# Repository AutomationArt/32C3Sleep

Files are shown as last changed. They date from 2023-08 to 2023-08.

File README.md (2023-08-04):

# 32C3Sleep for Automation.art
A framework for building your ESP32-c3 based projects. With battery charging and disconnection. 

#### Right away about bugs that were fixed in the scheme after the first prototype) 
!Resistors for the voltage divider should be taken 10kΩ and 39kΩ (R18 | R7), since the esp32c3 can measure 2.5V maximum

###  How does it work?
This board is designed to create projects in hibernation mode or with low power consumption and small size. Additional pins and JTAG are provided for this purpose. The TP4056 charging module discharges the battery in the same way as a self-discharging battery, and features a 3.3V LDO and an external quartz for more accurate timing.

### Main features
- Microcontroller with or without antenna
- Temperature sensor connection pins ds18b20
- Battery connection pins
- Reset button
- 1 indicator LEDs
- Ldo 3.3v

### Examples of use
- Sensor with low consumption and small size
- Any battery operated wifi/ble device
- ESP-NOW / WiFi-Mesh and other mesh technologies

### Current PCB release 
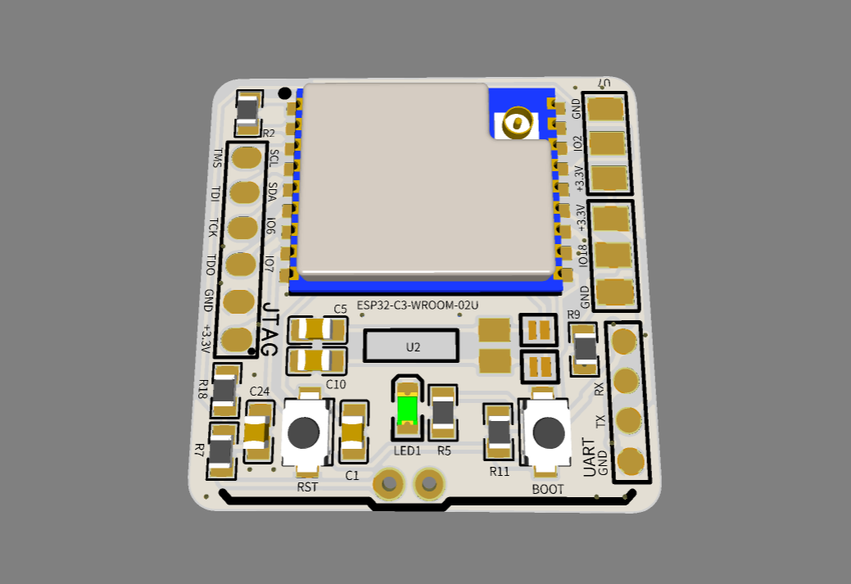
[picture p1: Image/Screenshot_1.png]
  
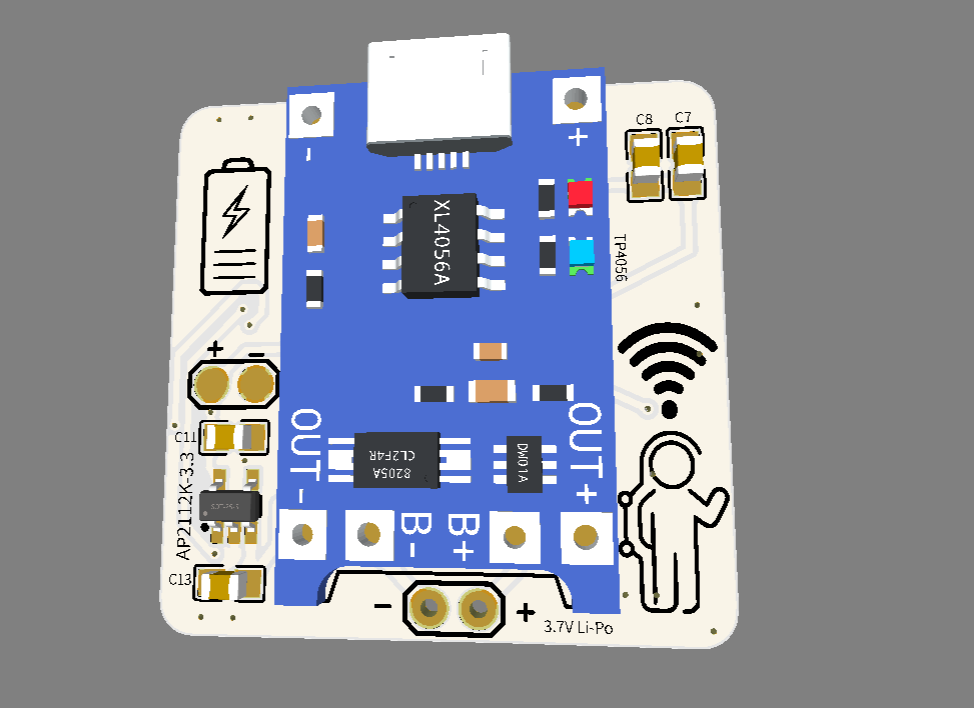
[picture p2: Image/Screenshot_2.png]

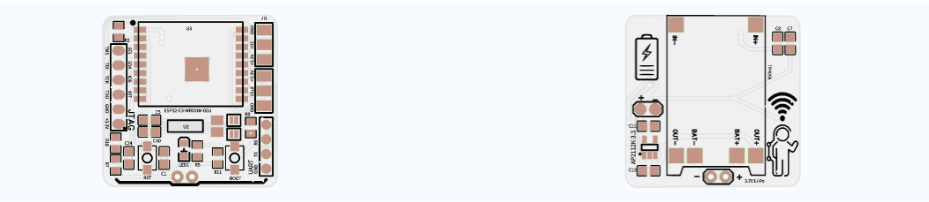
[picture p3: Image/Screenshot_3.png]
  

### Manufactured device 

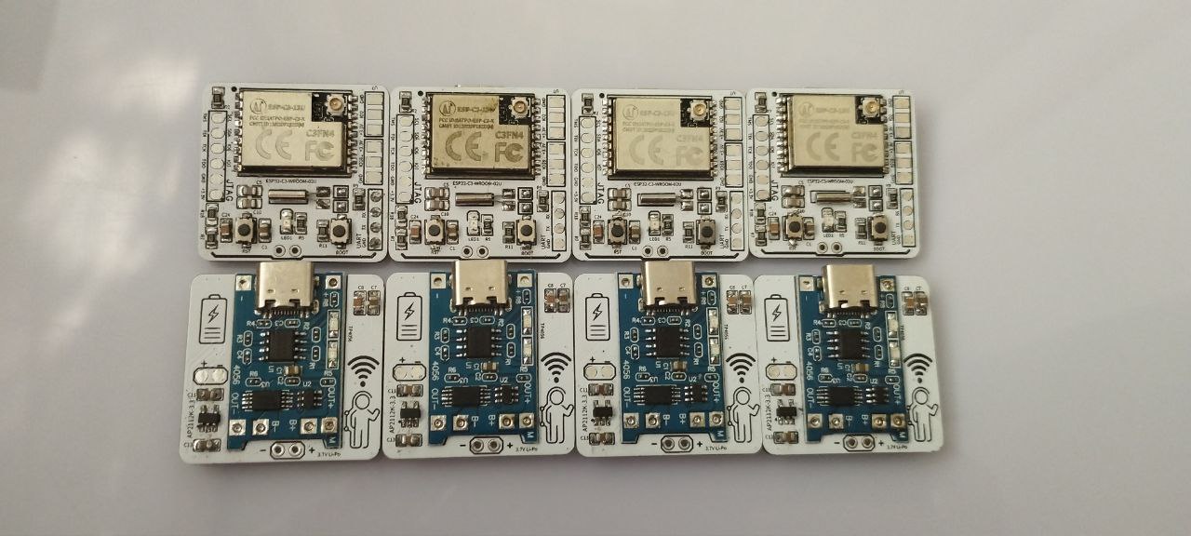
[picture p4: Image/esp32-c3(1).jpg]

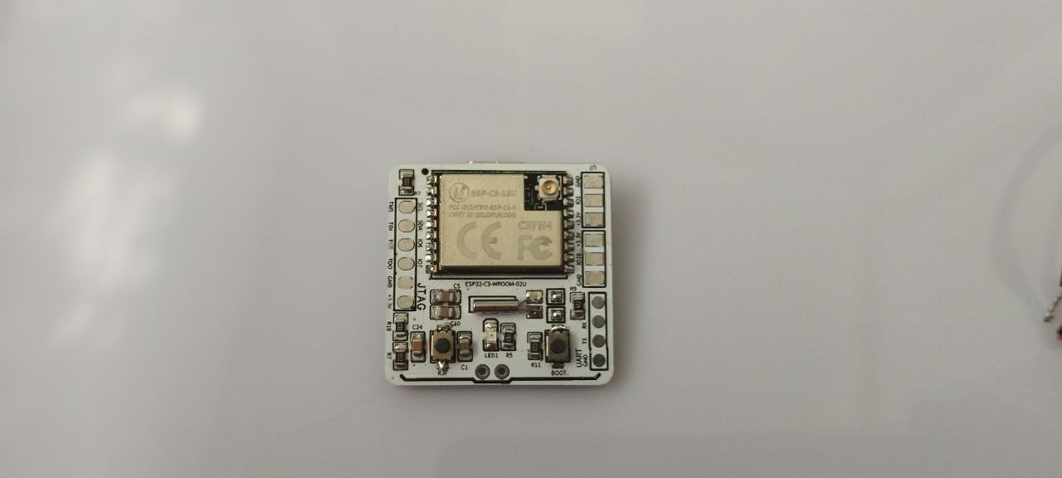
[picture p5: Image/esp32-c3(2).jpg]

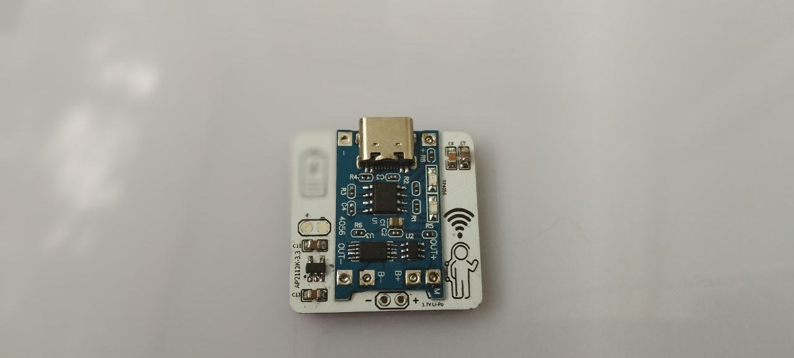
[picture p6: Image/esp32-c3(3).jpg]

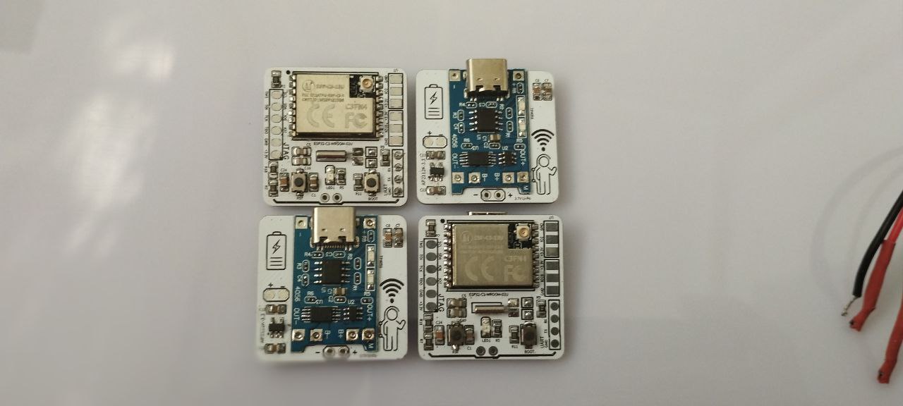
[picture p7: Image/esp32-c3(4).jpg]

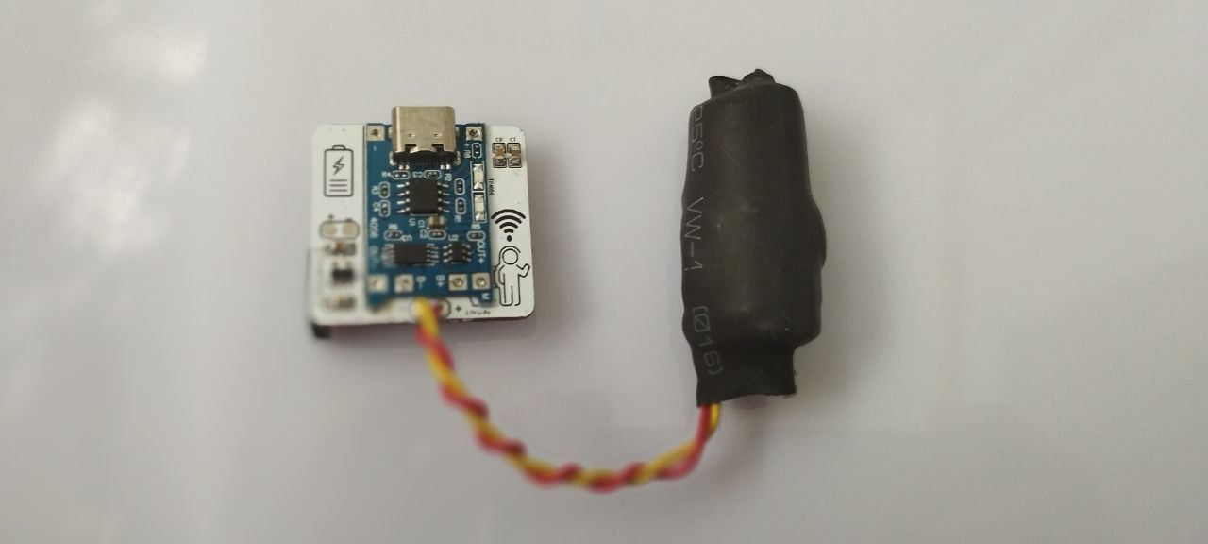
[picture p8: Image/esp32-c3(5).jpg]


### Case
The sample box for the board with 850mA battery is in the Case folder, the SKP model is there as well

### Specifications

| Name | Justification |
| --- | --- |
| ESP32-C3-WROOM-02U | This is a low-power, high-performance Wi-Fi and Bluetooth chip | 
| TP4056  | This is a battery charging controller that can be used to charge a variety of batteries, including LiPo, Li-Ion, and NiMH |
| AP2112K-3.3TRG1 | This is a buck converter that can be used to convert a higher voltage to a lower voltage.|
| 32.768K |  This is a crystal oscillator that can be used to generate a 32.768 kHz clock signal.  |
| LED0805 | This is an LED that is commonly used in electronic devices.

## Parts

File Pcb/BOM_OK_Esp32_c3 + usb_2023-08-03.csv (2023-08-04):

ID | Name | Designator | Footprint | Quantity | Manufacturer Part | Manufacturer | Supplier | Supplier Part | Price | Pins | Contributor | JLCPCB Part Class | Package Display | Resistance (Ohms) | link
1 | Boot/Flash | BOOT2 | SW-SMD_L4.0-W2.9-LS5.0 | 1 | Switch3x4x2 | ReliaPro | LCSC | C26638 |  | 2 |  | Extended Part
2 | 1uF | C1 | C0805 | 1 | C0402X5R105K350NT | SANYEAR(叁叶源) | LCSC | C968773 | 0.039 | 2 | LCSC | Extended Part
3 | 12pF | C5,C10 | C0805 | 2 | 0805J1K00120GCR | Knowles(楼氏) | LCSC | C2319497 | 0.212 | 2 | LCSC | Extended Part
4 | 10uF | C7 | C0805 | 1 | 0402X106M100NT | FH(风华) | LCSC | C2846677 | 0.016 | 2 | LCSC | Extended Part
5 | 100nF | C8 | C0805 | 1 | 0402B104K100CT | Walsin Tech Corp | LCSC | C387941 | 0.002 | 2 | LCSC | Extended Part
6 | 10uF | C11 | C0805 | 1 | CL10A106KP8NNNC | SAMSUNG | LCSC | C19702 | 0.006 | 2 |  | Basic Part | Yes
7 | 1uF | C13 | C0805 | 1 | CL10A105KB8NNNC | SAMSUNG | LCSC | C15849 | 0.006 | 2 |  | Basic Part | Yes
8 | 100nF | C24 | C0805 | 1 | CL10B104KA8NNNC | SAMSUNG | LCSC | C1590 | 0.003 | 2 |  | Extended Part | Yes
9 | XL-1005UYC | LED1 | LED0805-RD_YELLOW | 1 | XL-1005UYC | XINGLIGHT(成兴光) | LCSC | C965792 | 0.011 | 2 | LCSC | Extended Part
10 | 10kΩ | R2,R11 | R0805 | 2 | QR0402F10KQ10 | Ever Ohms Tech | LCSC | C176102 | 0.003 | 2 | LCSC | Extended Part |  | 10K
11 | 110Ω | R5 | R0805 | 1 | HPCR0402F110RK9 | ResistorToday | LCSC | C364834 | 0.004 | 2 | LCSC | Extended Part |  | 110
12 | 18kΩ | R7 | R0805 | 1 | 0603WAF2702T5E | UniOhm | LCSC | C22967 | 0.001 | 2 |  | Basic Part |  | 27K
13 | 4.7kΩ | R9 | R0805 | 1 | RMC04024.7K1%N | Tyohm | LCSC | C270129 | 0.002 | 2 | LCSC | Extended Part |  | 4.7K
14 | 30kΩ | R18 | R0805 | 1 | 0603WAF1003T5E | UniOhm | LCSC | C25803 | 0.001 | 2 |  | Basic Part |  | 100K
15 | Reset | RST1 | SW-SMD_L4.0-W2.9-LS5.0 | 1 | Switch3x4x2 | ReliaPro | LCSC | C26638 |  | 2 |  | Extended Part
16 | JTAG | U1 | PIN HEADER 1X6PIN 2.54MM 6P | 1 |  |  |  |  |  | 6 | FirstZ Kai Zen
17 | 32.768k | U2 | 32.768K 2*6 | 1 | 32.768k |  |  |  |  | 2 | пока покакович
18 | ESP32-C3-WROOM-02U | U3 | ESP32-C3-WROOM-02U | 1 |  | Espressif Systems |  |  |  | 19 | LCSC
19 | FLASH/UART | U4 | 4PINS | 1 |  |  |  |  |  | 4 | Chinz
20 | TP4056_MODULE COPY | U5 | TP4056MODULE | 1 |  |  |  |  |  | 6 | David Lochlin
21 | AP2112K-3.3TRG1 | U6 | SOT-25-5_L3.0-W1.8-P0.95-LS3.0-BR | 1 | AP2112K-3.3TRG1 | DIODES | LCSC | C51118 | 0.094 | 5 | LCSC | Extended Part | No
22 | IO2/ADC1_CH2 | U7 | 3 PIN SMD HEADER | 1 |  |  |  |  |  | 3 | szegabesz
23 | IO18 | U12 | 3 PIN SMD HEADER | 1 |  |  |  |  |  | 3 | szegabesz
24 | Battery_2Pin_Connector | X1 | BATTERY_2PIN_CONNECTOR | 1 |  |  |  |  |  | 2 | Uladzimir Sokalau
25 | Capacitor | X2 | BATTERY_2PIN_CONNECTOR | 1 |  |  |  |  |  | 2 | Uladzimir Sokalau

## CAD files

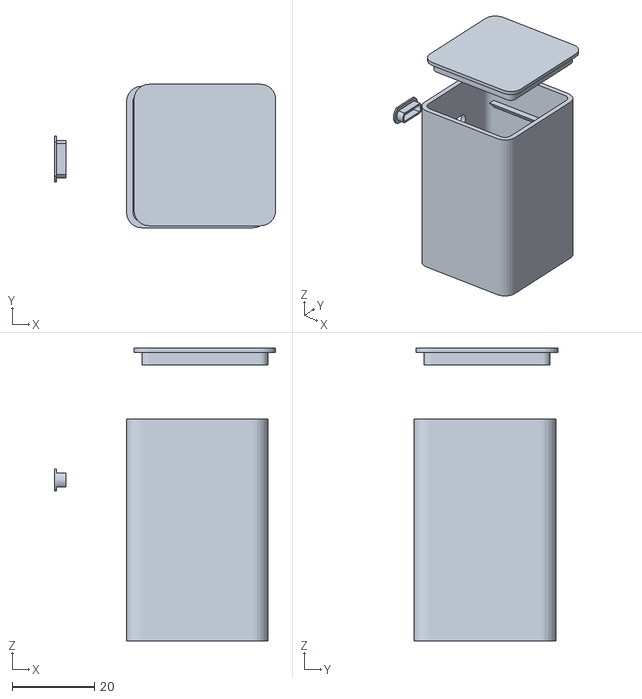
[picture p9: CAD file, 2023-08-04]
Case/esp32c3_case.stl
53.7 x 34.8 x 71.0

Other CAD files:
Case/esp32c3_case.skp

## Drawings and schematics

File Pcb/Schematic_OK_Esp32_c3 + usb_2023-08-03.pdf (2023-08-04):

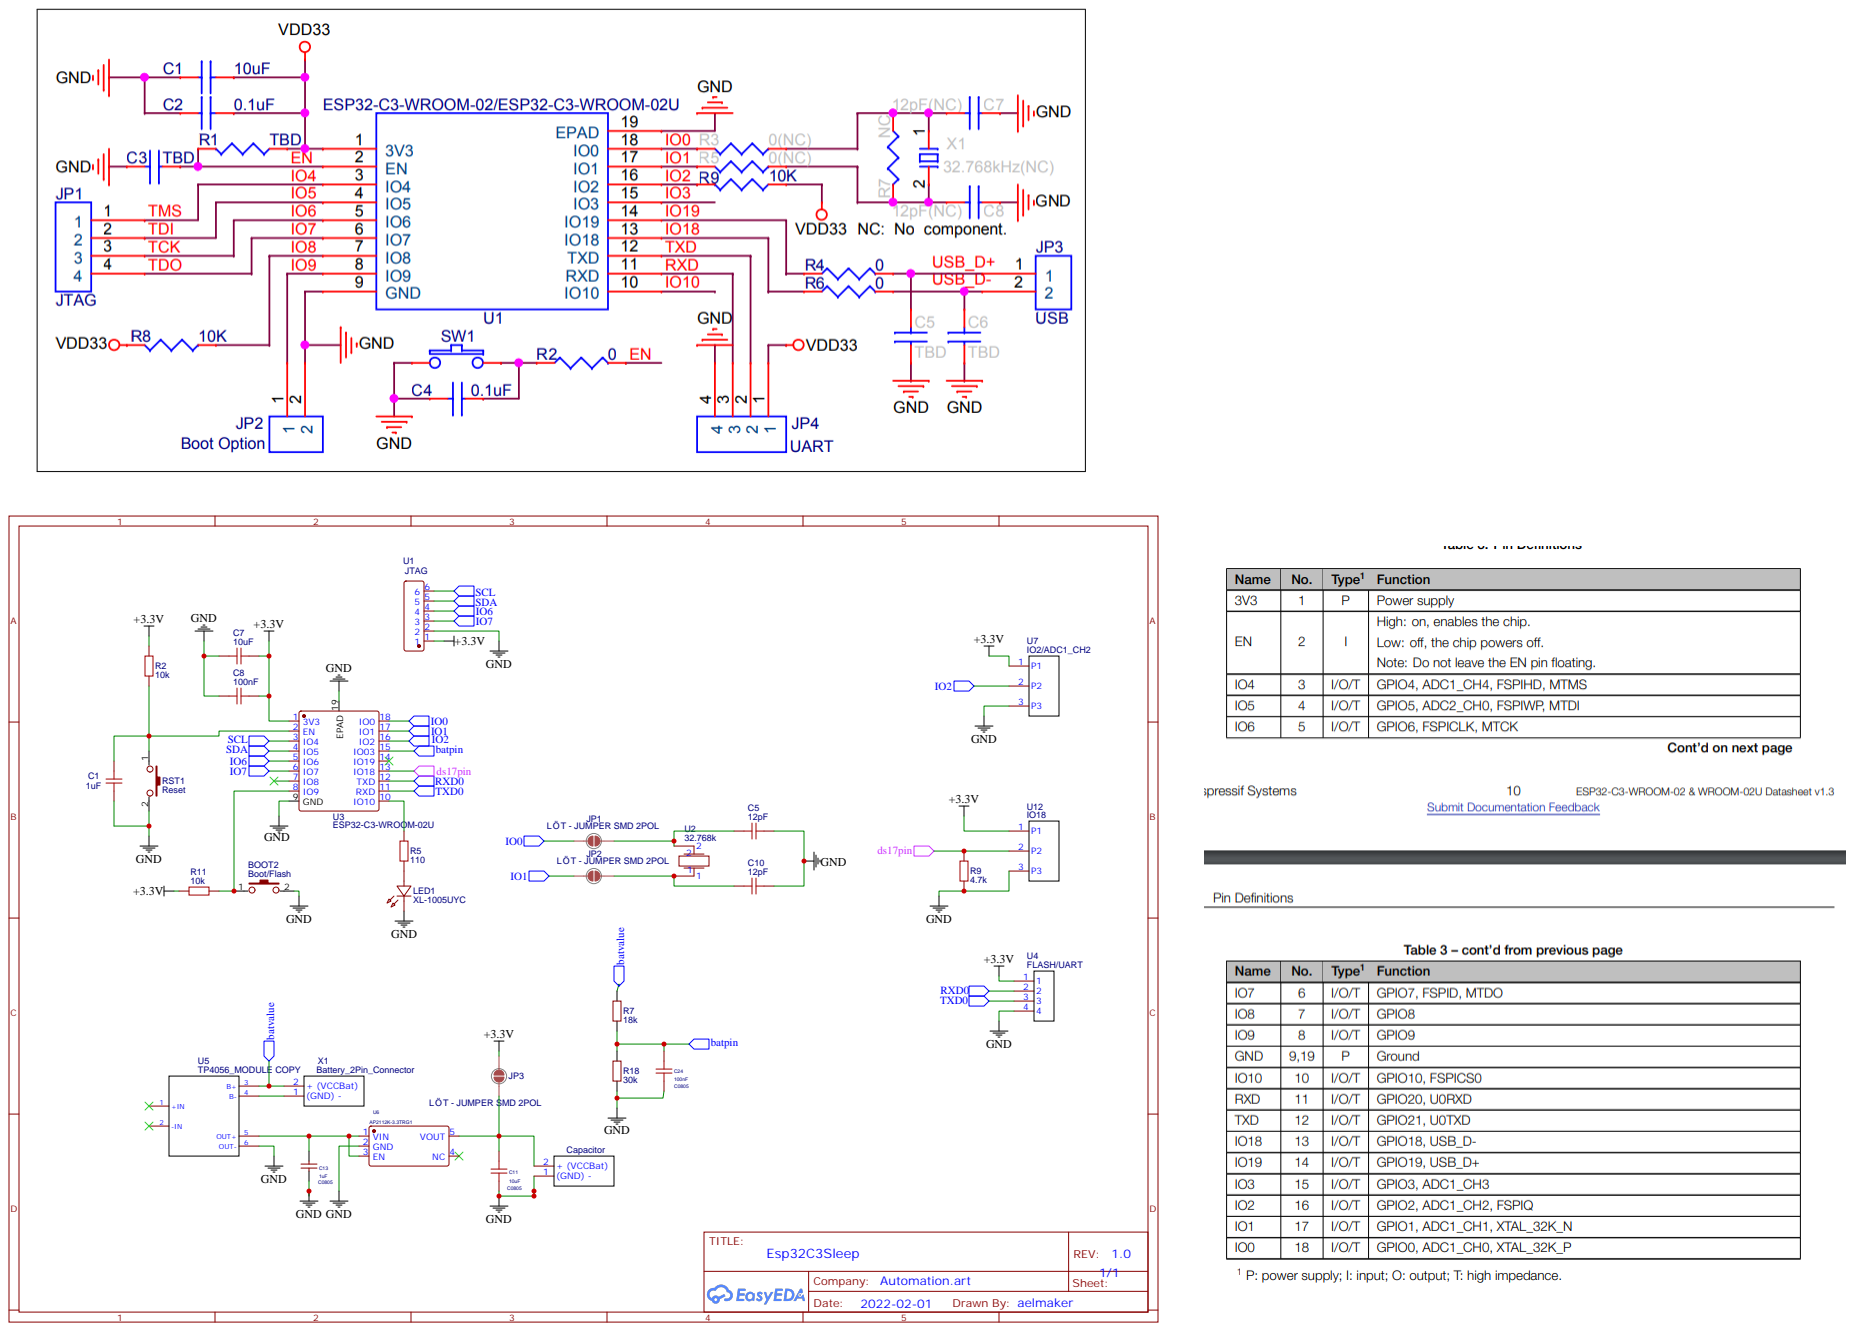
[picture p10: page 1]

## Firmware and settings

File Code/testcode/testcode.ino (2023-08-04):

#define BatValuePin 3
#define LedPin 10
#define ds18Pin 18
#define ADC1_CH2 2
#define Freepin 6
#define Freepin 7

float readAnalogVoltage() {
  pinMode(BatValuePin, INPUT);
  int analogValue = analogRead(BatValuePin);
  float voltage = analogValue * 2.5 / 4095;
  return map(voltage, 0, 2.5, 2.7, 4.2);
}

int ledControl(int state) {
  pinMode(LedPin, OUTPUT);
  digitalWrite(LedPin, state);
  return 0;
}

void setup() {
  Serial.begin(115200); 
}

void loop() {
  Serial.println(readAnalogVoltage);
  ledControl(true);
  delay(200); 
  ledControl(false);

  delay(1000);
}
